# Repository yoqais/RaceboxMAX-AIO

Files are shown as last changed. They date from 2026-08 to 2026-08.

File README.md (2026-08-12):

# RaceboxMAX AIO

Wireless display and lap/drag timer for the RaceBox Micro. An ESP32-C6 reads
the logger's 25 Hz BLE telemetry and shows live speed, G-forces, lap times
and drag runs on a 2.42" SSD1309 OLED. Powered by a single 18650.

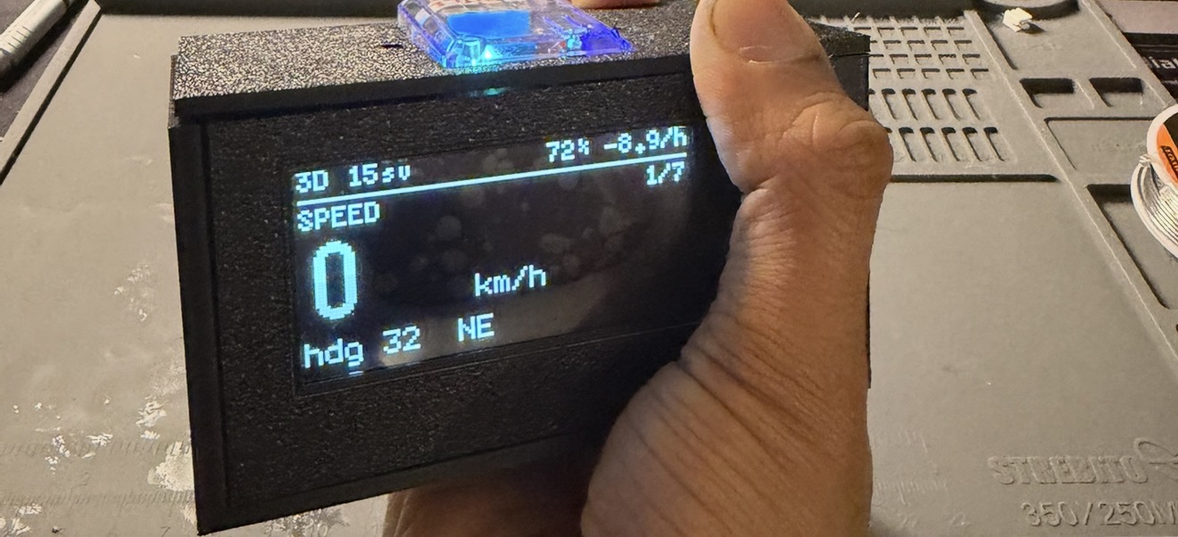
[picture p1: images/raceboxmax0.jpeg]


## Hardware

| Qty | Part | Notes |
|---|---|---|
| 1 | RaceBox Micro | The instrument. Accepts 3.5–16 V, draws ~25 mA recording |
| 1 | Seeed XIAO ESP32-C6 | 21 x 17.5 mm, BLE 5.3, USB-C |
| 1 | 2.42" SSD1309 OLED | 128 x 64, I2C mode, address 0x3C |
| 1 | Adafruit MAX17048 | LiPo fuel gauge, I2C, address 0x36 |
| 1 | Adafruit PowerBoost 1000C | 1 A charger, 5.2 V boost, load sharing |
| 1 | Protected 18650 | 3400 mAh. Protected cells run 69–70 mm, check holder fit |
| 1 | 470 uF electrolytic | Bulk cap across the XIAO's VBUS and GND |
| 3 | 6 x 6 mm tactile switch | Up, down, select |
| 1 | SPST toggle | Master power, wired to the PowerBoost EN pin |

No fuses and no external resistors. The protected cell's own PCB opens a
short in tens of microseconds, while a PPTC takes tens of milliseconds and
would never win that race. The I2C pull-ups are already on both breakouts.

## Wiring

The 18650 goe through the MAX17048's two parallel JST connectors into the
PowerBoost battery input, so the gauge sees the cell without sitting in the
way of anything. The PowerBoost 5.2 V rail feeds the XIAO's VBUS pin and the
RaceBox in parallel. Everything on I2C runs from the XIAO's 3V3 pin so the
logic levels match the C6's 3.3 V GPIO.

| Signal | XIAO pin | GPIO |
|---|---|---|
| I2C SDA | D4 | 22 |
| I2C SCL | D5 | 23 |
| Display RES | D3 | 21 |
| Button UP | D0 | 0 |
| Button DOWN | D1 | 1 |
| Button SELECT | D2 | 2 |

The display's DC and CS pads tie to ground. The XIAO's own BAT solder pads
stay empty, because the PowerBoost is the charger and two charger ICs on one
cell will fight each other.

The 470 uF cap goes as close to the XIAO's VBUS and GND pins as you can
solder it. The C6 pulls sharp current bursts on radio activity, and the sag
down a foot of wire causes brownout resets that look exactly like a firmware
bug. Watch polarity.

### Ground

Ground is one net, but three separate buses:

| Bus | Fed from | Carries |
|---|---|---|
| GND-A | PowerBoost G pin | XIAO, bulk cap |
| GND-C | XIAO GND pin | Display, fuel gauge |
| GND-B | PowerBoost GND pin | RaceBox, switch, buttons |

The I2C peripherals ground at the XIAO rather than at the PowerBoost. The C6
pulls roughly 300 mA in short bursts during radio activity and that current
has to return somewhere. Referencing the display and gauge to the same point
as their bus master makes any resulting offset common mode instead of putting
it across SDA and SCL.

## Power

| Load | On the 5.2 V rail |
|---|---|
| XIAO ESP32-C6 | ~70 mA |
| SSD1309 | ~50 mA depending on lit pixels |
| RaceBox Micro | ~25 mA |

Roughly 145 mA out, about 230 mA from the cell once boost losses and
quiescent draw are counted. That gives somewhere near 12 hours on a 3400 mAh
cell.

## Interface

Up, down and select. A 600 ms long-press on select backs out from anywhere.

A status bar is drawn across the top of every screen and no page can write
into it. It shows fix type and satellite count on the left, battery percent
and discharge rate in percent per hour on the right. The battery text is
right-aligned by measured width and the left label is suppressed if it would
not fit, so the two can never collide.

### Live page

Speed in MPH as the headline number, with lateral and longitudinal G,
heading and compass point, altitude, and horizontal accuracy underneath.

### Track page
Select a track and the display arms itself. Drive across the start/finish
line and timing begins automatically. Every crossing after that closes one
lap and opens the next. While running you get current lap, last lap and best
lap, with a checkered flag on a new personal best.

Thunderhill East 3 mile, West 2 mile and the 5 mile combined are preloaded.

**Before your first session**, each track needs its start/finish line
recorded. Gate coordinates ship empty because a gate has to be accurate to a
few metres and there is no useful default.

1. Select the track. The screen will read NO GATE SET.
2. Drive to the start/finish line, pointing the direction you race.
3. Press UP. The firmware builds a 30 m gate perpendicular to your heading
   and begins timing immediately.
4. Check the serial monitor. It prints the gate ready to paste into the
   tracks table so it survives a power cycle.

Captured gates live in RAM and clear on reboot until you paste them in.
Uploading tracks and gates from the menu is planned for a future update.

```
{ "T-Hill 5 Mile",  39.5372, -122.3310,  3.0f,  {0, 0, 0, 0, false} }
//     name       center lat  center lon  radius      gate
```

The center coordinates in the table are approximate and used only for the
proximity check with a 3 km radius. They are not accurate enough to be gates.

### Drag page

Standing start auto-arms after one second stationary and triggers on
movement, so there is no button press at the line. It captures 60 ft,
0–60 mph, and eighth and quarter mile with trap speeds, integrating distance
from speed against iTOW deltas.

A separate 60–0 mode arms above 62 mph, starts measuring when you drop
through 60, and reports braking distance in feet.

There is no rollout correction, so these read 0.2 to 0.3 s slower than a
dragstrip slip, which starts the clock after the car rolls a foot.

### Options page

State of charge, cell voltage, charge rate in percent per hour, hours
remaining, and the gauge's IC version, chip ID and alert flags.

## Firmware notes

Both timers run inside the BLE notify callback rather than the main loop, so
no 25 Hz sample is dropped while the display is mid-redraw.

Notifications are reassembled by a byte-level state machine that syncs on the
0xB5 0x62 header, reads the declared payload length, and verifies the
checksum before parsing. BLE can split an 88-byte message across fragments,
and assuming one notification equals one packet will bite you.

All field extraction uses memcpy rather than pointer casts. Reference code
written for the original ESP32 casts unaligned pointers, which works on
Xtensa because it has an unaligned-access exception handler. The C6 is
RISC-V.

The C6 has a dual-antenna design with an RF switch on GPIO14. Get that wrong
and BLE range collapses in a way that is maddening to debug.

### Libraries

- U8g2 by oliver
- Adafruit MAX1704X
- NimBLE-Arduino **2.x**

NimBLE 1.4.x will not compile on Arduino core 3.x. It was built against
ESP-IDF 4.4 and fails on a missing `esp_coexist_internal.h`. The C6 only
exists on core 3.x, so 2.x is the only option.

## Enclosure

Printed in PETG, six parts: screen face, enclosure body, enclosure lid, button backings, esp326c tray,
MAX17048 tray and PowerBoost tray.

Do not print in anything carbon-filled. The XIAO's BLE antenna is inside the
box and carbon fiber is conductive enough to kill it.

The RaceBox mounts on top of the case, outside, because its patch antenna
needs a clear view of the sky while the display needs to face the driver.
Those are 90 degrees apart and no arrangement satisfies both in one sealed
box. Metal below a patch antenna is harmless, metal above or beside it is
not, which is why the 18650 lives in the bottom compartment.

## What it does not do

It does not record anything. No SD card, no filesystem, no NVS. Best lap and
best drag times live in RAM and clear on power cycle. Captured gates do the
same, which is why they print to serial.

Downloading the RaceBox's internal recordings over BLE is possible and
documented in their protocol. The device streams History Data messages after
an unlock, and the lock state resets on every connection. It is not
implemented here because there is nowhere to put two hours of 25 Hz data
without adding storage.

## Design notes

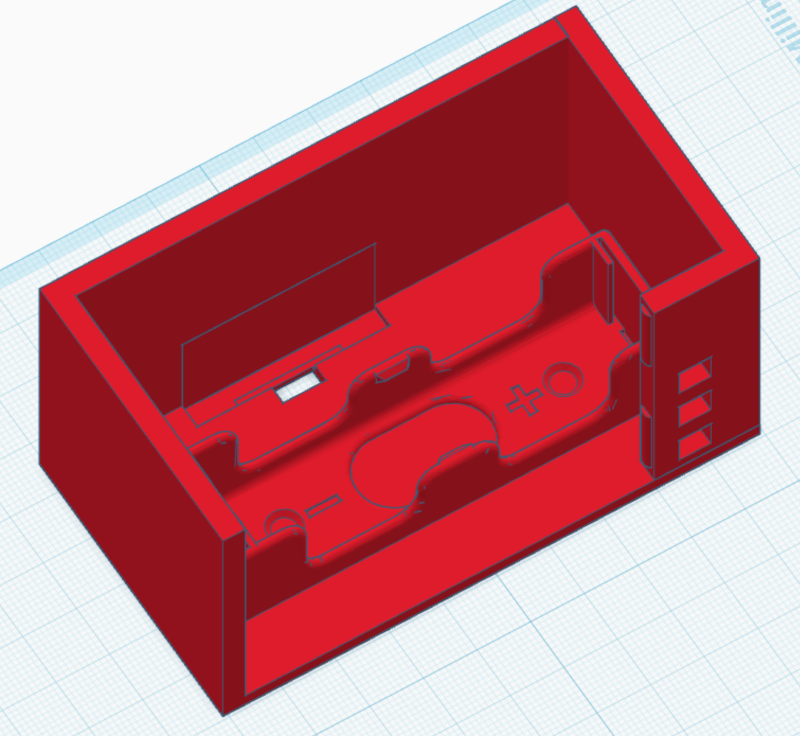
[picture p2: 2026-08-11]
images/housing.png

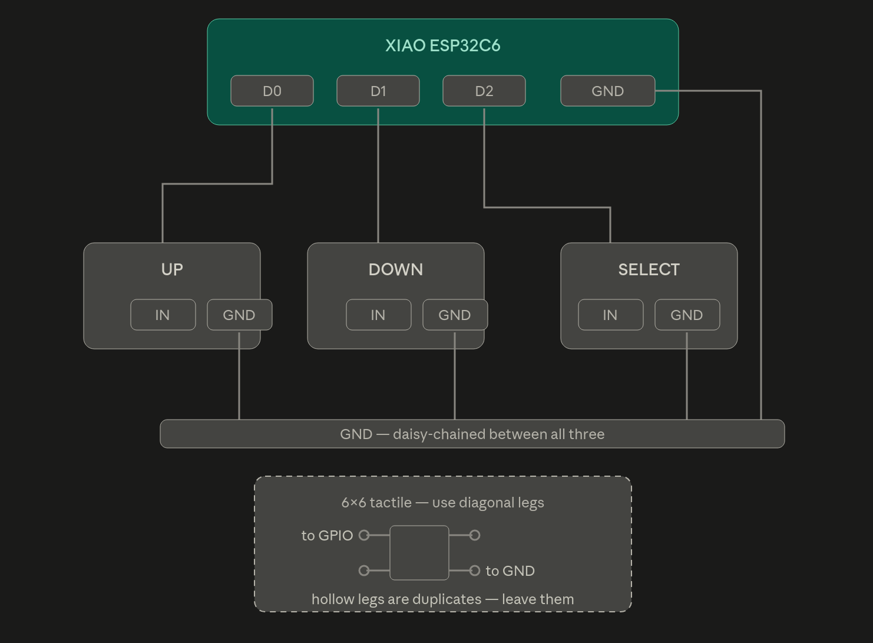
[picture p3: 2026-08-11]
diagrams/BTN_diagram.png

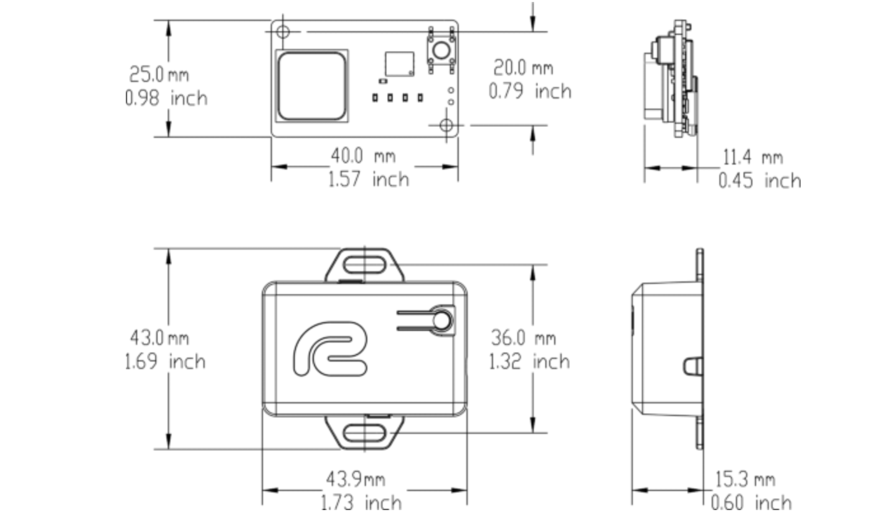
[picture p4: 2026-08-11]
diagrams/raceboxmicro_dimensions.png

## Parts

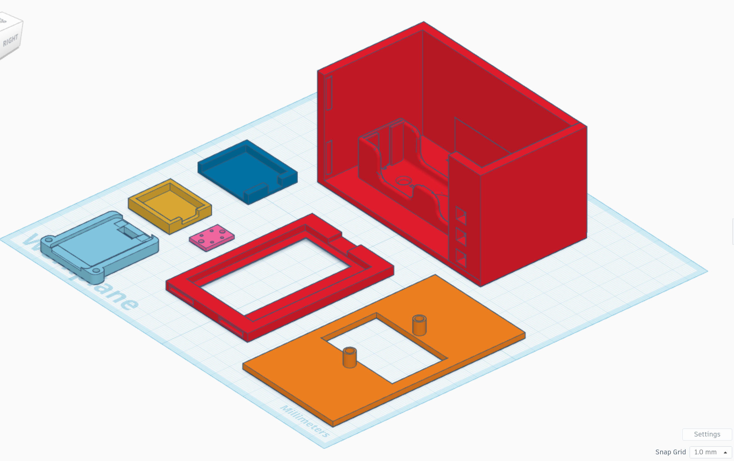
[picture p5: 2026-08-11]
images/parts.png

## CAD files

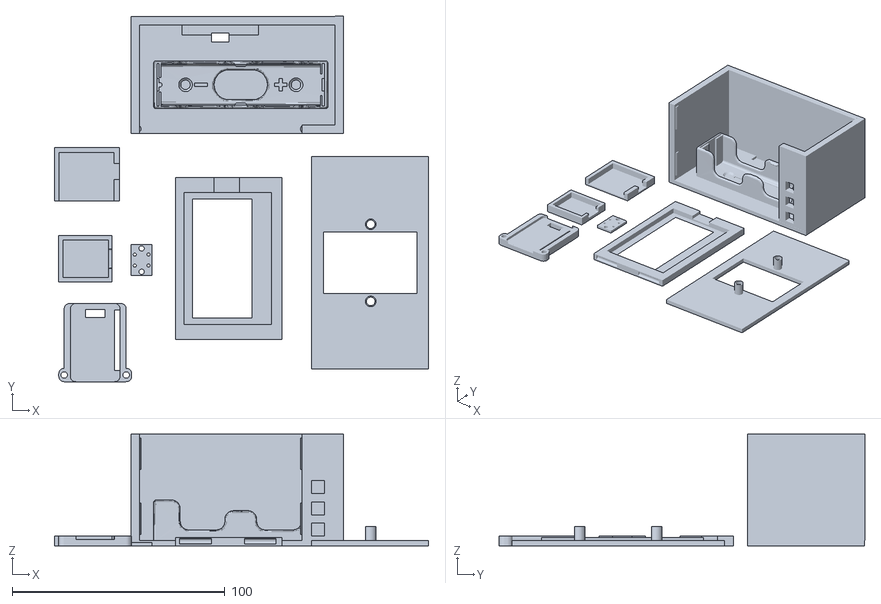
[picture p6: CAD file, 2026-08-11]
RaceboxMAX.stl
176.0 x 172.0 x 52.5

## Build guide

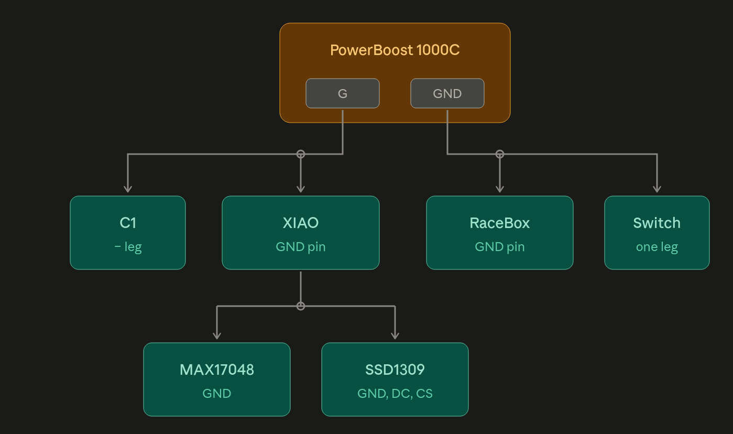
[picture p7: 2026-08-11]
diagrams/Wiring_Grounds_diagram.png

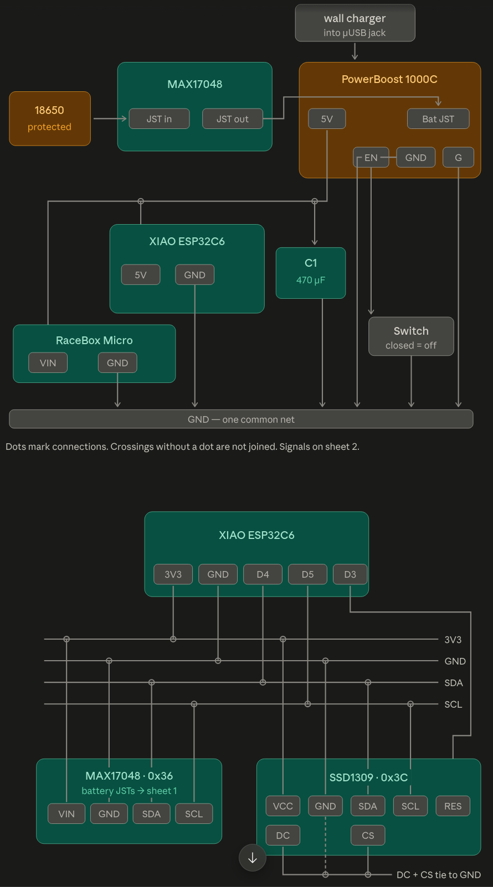
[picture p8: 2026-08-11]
diagrams/Wiring_Diagram.png

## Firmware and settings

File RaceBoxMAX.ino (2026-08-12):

#include <Wire.h>
#include <U8g2lib.h>
#include <Adafruit_MAX1704X.h>
#include <NimBLEDevice.h>
#include <string.h>
#include <math.h>

#define PIN_SDA        D4
#define PIN_SCL        D5
#define PIN_OLED_RES   D3
#define PIN_BTN_UP     D0
#define PIN_BTN_DOWN   D1
#define PIN_BTN_SELECT D2

// -------------------------------------------------------------- settings --
// Paste your RaceBox address here once you have it, e.g. "d1:9a:44:0f:22:31"
static const char* TARGET_ADDRESS = "";

static const uint32_t ADDRESS_HOLD_MS  = 5000;
static const uint32_t DRAW_INTERVAL_MS = 100;
static const uint32_t GAUGE_INTERVAL_MS = 1000;
static const uint32_t GAUGE_SETTLE_MS  = 2500;
static const uint32_t DEBOUNCE_MS      = 25;
static const uint32_t LONGPRESS_MS     = 600;
static const uint32_t MIN_LAP_MS       = 10000;   // ignore re-triggers
static const float    GATE_HALF_WIDTH_M = 15.0f;  // captured gates: 30 m wide

// ----------------------------------------------------------- BLE objects --
static NimBLEUUID UART_SERVICE_UUID("6E400001-B5A3-F393-E0A9-E50E24DCCA9E");
static NimBLEUUID TX_CHAR_UUID     ("6E400003-B5A3-F393-E0A9-E50E24DCCA9E");

U8G2_SSD1309_128X64_NONAME0_F_HW_I2C u8g2(U8G2_R0, PIN_OLED_RES, PIN_SCL, PIN_SDA);
Adafruit_MAX17048 gauge;

// ================================================================ screens ==
enum Screen {
  SC_SCAN, SC_ADDR, SC_LOST,
  SC_MAIN, SC_LIVE,
  SC_TRACKLIST, SC_TRACKRUN,
  SC_DRAGLIST, SC_DRAGRUN,
  SC_OPTIONS, SC_BATTERY
};
volatile Screen screen = SC_SCAN;

static const char* MAIN_ITEMS[]  = {"Live", "Track", "Drag", "Options"};
static const char* TRACK_ITEMS[] = {"< Back", "T-Hill East 3mi",
                                    "T-Hill West 2mi", "T-Hill 5 Mile"};
static const char* DRAG_ITEMS[]  = {"< Back", "Standing start",
                                    "60-0 braking", "Clear bests"};
static const char* OPT_ITEMS[]   = {"< Back", "Battery"};

uint8_t selMain = 0,  topMain = 0;
uint8_t selTrack = 0, topTrack = 0;
uint8_t selDrag = 0,  topDrag = 0;
uint8_t selOpt = 0,   topOpt = 0;

// ================================================================= tracks ==
struct Gate { double lat1, lon1, lat2, lon2; bool valid; };
struct TrackDef {
  const char* name;
  double cLat, cLon;      // approximate facility centre, proximity check only
  float  radiusKm;
  Gate   gate;
};

// Thunderhill Raceway Park, Willows CA. Centre is approximate and used ONLY
// to decide "are we at the track". Gates must be captured or hard-coded.
TrackDef tracks[] = {
  { "T-Hill East 3mi", 39.5372, -122.3310, 3.0f, {0,0,0,0,false} },
  { "T-Hill West 2mi", 39.5372, -122.3310, 3.0f, {0,0,0,0,false} },
  { "T-Hill 5 Mile",   39.5372, -122.3310, 3.0f, {0,0,0,0,false} },
};
const uint8_t TRACK_COUNT = sizeof(tracks) / sizeof(tracks[0]);
int8_t activeTrack = -1;

// ============================================================ live values ==
bool gaugeOK = false, displayOK = false;
float batPct = 0, batVolt = 0, batRate = 0;
uint16_t batIC = 0; uint8_t batChip = 0, batAlert = 0;

volatile bool connected = false, doConnect = false;
static NimBLEAddress targetAddr;
static bool haveTarget = false;
static NimBLERemoteCharacteristic* pTxChar = nullptr;
static NimBLEClient* pClient = nullptr;
char rbAddress[24] = "--:--:--:--:--:--";
char rbName[28]    = "unknown";
uint32_t addressShownAt = 0;

uint32_t rb_iTOW;
uint16_t rb_year; uint8_t rb_month, rb_day, rb_hour, rb_min, rb_sec;
uint8_t  rb_fixStatus, rb_numSVs, rb_battRaw;
int32_t  rb_lon, rb_lat, rb_mslAlt;
uint32_t rb_hAcc, rb_speed, rb_heading;
uint16_t rb_pdop;
int16_t  rb_gx, rb_gy, rb_gz, rb_rx, rb_ry, rb_rz;
uint32_t rbPackets = 0;

// ============================================================ lap timing ===
struct LapState {
  bool     havePrev;
  double   prevX, prevY;
  uint32_t prevITOW;
  bool     running;
  uint32_t startITOW;
  uint32_t lastLapMs, bestLapMs;
  uint16_t lapCount;
  bool     newBest;
  uint32_t newBestAt;
} lap;

// ============================================================ drag timing ==
enum DragMode  { DM_STANDING, DM_BRAKE };
enum DragState { DS_WAIT, DS_ARMED, DS_RUN, DS_DONE };
DragMode  dragMode  = DM_STANDING;
volatile DragState dragState = DS_WAIT;

struct DragRun {
  uint32_t t0;            // iTOW at launch / brake start
  double   dist;          // metres travelled
  uint32_t prevITOW;
  float    t60ft, t0_60, t1_8, t1_4;
  float    v1_8, v1_4;
  float    brakeDistFt, brakeFromMph;
  uint32_t stillSince;
} run;

float bestT0_60 = 0, bestT1_4 = 0, bestBrakeFt = 0;

// =========================================================== button types ==
// These MUST stay above the first function definition in the file. The
// Arduino IDE injects auto-generated prototypes just before the first
// function, so any type used in a signature has to already exist by then.
enum BtnEvent { EV_NONE, EV_UP, EV_DOWN, EV_SELECT, EV_BACK };

struct Btn {
  uint8_t pin; bool stable; bool lastRaw;
  uint32_t changedAt, pressedAt; bool longSent;
};
Btn bUp {PIN_BTN_UP,     true, true, 0, 0, false};
Btn bDn {PIN_BTN_DOWN,   true, true, 0, 0, false};
Btn bSel{PIN_BTN_SELECT, true, true, 0, 0, false};

// ================================================== safe field extraction ==
static inline uint16_t rdU16(const uint8_t* p){ uint16_t v; memcpy(&v,p,2); return v; }
static inline int16_t  rdI16(const uint8_t* p){ int16_t  v; memcpy(&v,p,2); return v; }
static inline uint32_t rdU32(const uint8_t* p){ uint32_t v; memcpy(&v,p,4); return v; }
static inline int32_t  rdI32(const uint8_t* p){ int32_t  v; memcpy(&v,p,4); return v; }

// ==================================================== unit helpers ========
float speedMps()  { return rb_speed / 1000.0f; }
float speedMph()  { return rb_speed * 0.00223694f; }
float headingDeg(){ return rb_heading / 100000.0f; }
float latG()      { return rb_gy / 1000.0f; }
float lonG()      { return rb_gx / 1000.0f; }
float rbInputV()  { return rb_battRaw / 10.0f; }
bool  haveFix()   { return rb_fixStatus == 3 || rb_fixStatus == 2; }

const char* compass(float d) {
  static const char* p[] = {"N","NE","E","SE","S","SW","W","NW"};
  return p[((int)((d + 22.5f) / 45.0f)) & 7];
}
const char* fixText(uint8_t f) {
  switch (f) { case 0: return "nofix"; case 2: return "2D"; case 3: return "3D"; }
  return "?";
}

// local flat projection, good to millimetres over a few km
static void projectTo(double lat, double lon, double lat0, double lon0,
                      double &x, double &y) {
  const double M_PER_DEG = 111320.0;
  x = (lon - lon0) * M_PER_DEG * cos(lat0 * M_PI / 180.0);
  y = (lat - lat0) * M_PER_DEG;
}

static double distanceKm(double la1, double lo1, double la2, double lo2) {
  double x, y;
  projectTo(la1, lo1, la2, lo2, x, y);
  return sqrt(x * x + y * y) / 1000.0;
}

// ==================================================== packet reassembly ====
#define PKT_MAX 160
static uint8_t pkt[PKT_MAX];
static size_t  pktLen = 0;

static bool checksumOK(const uint8_t* d, size_t len) {
  uint8_t a = 0, b = 0;
  for (size_t i = 2; i < len - 2; i++) { a += d[i]; b += a; }
  return (a == d[len - 2] && b == d[len - 1]);
}

void updateLapTiming();
void updateDrag();

static void parseDataMessage(const uint8_t* d) {
  rb_iTOW   = rdU32(d + 6);
  rb_year   = rdU16(d + 10);
  rb_month  = d[12]; rb_day = d[13];
  rb_hour   = d[14]; rb_min = d[15]; rb_sec = d[16];
  rb_fixStatus = d[26];
  rb_numSVs    = d[29];
  rb_lon    = rdI32(d + 30);
  rb_lat    = rdI32(d + 34);
  rb_mslAlt = rdI32(d + 42);
  rb_hAcc   = rdU32(d + 46);
  rb_speed  = rdU32(d + 54);
  rb_heading= rdU32(d + 58);
  rb_pdop   = rdU16(d + 70);
  rb_battRaw= d[73];
  rb_gx = rdI16(d + 74); rb_gy = rdI16(d + 76); rb_gz = rdI16(d + 78);
  rb_rx = rdI16(d + 80); rb_ry = rdI16(d + 82); rb_rz = rdI16(d + 84);
  rbPackets++;

  // run the timers here so no 25 Hz sample is ever missed
  if (screen == SC_TRACKRUN) updateLapTiming();
  if (screen == SC_DRAGRUN)  updateDrag();
}

static void handlePacket(const uint8_t* d, size_t len) {
  if (d[2] == 0xFF && d[3] == 0x01 && rdU16(d + 4) == 80) parseDataMessage(d);
}

static void feedByte(uint8_t b) {
  if (pktLen >= PKT_MAX) pktLen = 0;
  if (pktLen == 0) { if (b == 0xB5) pkt[pktLen++] = b; return; }
  if (pktLen == 1) {
    if (b == 0x62) pkt[pktLen++] = b;
    else if (b != 0xB5) pktLen = 0;
    return;
  }
  pkt[pktLen++] = b;
  if (pktLen >= 6) {
    size_t total = 6 + rdU16(pkt + 4) + 2;
    if (total > PKT_MAX) { pktLen = 0; return; }
    if (pktLen == total) {
      if (checksumOK(pkt, total)) handlePacket(pkt, total);
      pktLen = 0;
    }
  }
}

// ============================================== gate crossing detection ====
// Segment/segment intersection. t = fraction along the path segment.
static bool segIntersect(double ax,double ay,double bx,double by,
                         double cx,double cy,double dx,double dy, double &t) {
  double rx = bx-ax, ry = by-ay, sx = dx-cx, sy = dy-cy;
  double den = rx*sy - ry*sx;
  if (fabs(den) < 1e-12) return false;
  double tt = ((cx-ax)*sy - (cy-ay)*sx) / den;
  double uu = ((cx-ax)*ry - (cy-ay)*rx) / den;
  if (tt < 0 || tt > 1 || uu < 0 || uu > 1) return false;
  t = tt;
  return true;
}

void resetLap() {
  memset(&lap, 0, sizeof(lap));
}

void updateLapTiming() {
  if (activeTrack < 0) return;
  Gate &g = tracks[activeTrack].gate;
  if (!g.valid || !haveFix()) { lap.havePrev = false; return; }

  double lat = rb_lat / 1e7, lon = rb_lon / 1e7;
  double lat0 = (g.lat1 + g.lat2) * 0.5, lon0 = (g.lon1 + g.lon2) * 0.5;

  double px, py;  projectTo(lat, lon, lat0, lon0, px, py);
  double g1x, g1y, g2x, g2y;
  projectTo(g.lat1, g.lon1, lat0, lon0, g1x, g1y);
  projectTo(g.lat2, g.lon2, lat0, lon0, g2x, g2y);

  if (!lap.havePrev) {
    lap.havePrev = true;
    lap.prevX = px; lap.prevY = py; lap.prevITOW = rb_iTOW;
    return;
  }

  double t;
  if (segIntersect(lap.prevX, lap.prevY, px, py, g1x, g1y, g2x, g2y, t)) {
    // interpolate the exact crossing instant between the two 25 Hz samples
    int32_t dt = (int32_t)(rb_iTOW - lap.prevITOW);
    uint32_t cross = lap.prevITOW + (uint32_t)(t * dt);

    if (lap.running) {
      uint32_t lapMs = cross - lap.startITOW;
      if (lapMs >= MIN_LAP_MS) {
        lap.lastLapMs = lapMs;
        lap.lapCount++;
        if (lap.bestLapMs == 0 || lapMs < lap.bestLapMs) {
          lap.bestLapMs = lapMs;
          lap.newBest = true;
          lap.newBestAt = millis();
        }
        lap.startITOW = cross;
      }
    } else {
      lap.running = true;
      lap.startITOW = cross;
      lap.lapCount = 0;
    }
  }

  lap.prevX = px; lap.prevY = py; lap.prevITOW = rb_iTOW;
}

// build a gate perpendicular to the current heading, centred here
void captureGate() {
  if (activeTrack < 0 || !haveFix()) return;
  double lat = rb_lat / 1e7, lon = rb_lon / 1e7;
  double hdg = headingDeg() * M_PI / 180.0;

  // perpendicular unit vector in metres
  double px = cos(hdg), py = -sin(hdg);          // right-hand normal
  double mLat = GATE_HALF_WIDTH_M / 111320.0;
  double mLon = GATE_HALF_WIDTH_M / (111320.0 * cos(lat * M_PI / 180.0));

  Gate &g = tracks[activeTrack].gate;
  g.lat1 = lat + py * mLat;  g.lon1 = lon + px * mLon;
  g.lat2 = lat - py * mLat;  g.lon2 = lon - px * mLon;
  g.valid = true;

  resetLap();
  Serial.printf("GATE %s\n  {%.7f, %.7f, %.7f, %.7f, true}\n",
                tracks[activeTrack].name, g.lat1, g.lon1, g.lat2, g.lon2);
}

// ===================================================== drag mode timing ====
void resetDrag() {
  memset(&run, 0, sizeof(run));
  dragState = DS_WAIT;
}

void updateDrag() {
  float mph = speedMph();
  uint32_t now = rb_iTOW;

  if (dragMode == DM_STANDING) {
    switch (dragState) {
      case DS_WAIT:
        if (mph < 1.0f) {
          if (run.stillSince == 0) run.stillSince = now;
          if (now - run.stillSince > 1000) { dragState = DS_ARMED; }
        } else run.stillSince = 0;
        break;

      case DS_ARMED:
        if (mph > 1.0f) {
          memset(&run, 0, sizeof(run));
          run.t0 = now; run.prevITOW = now;
          dragState = DS_RUN;
        }
        break;

      case DS_RUN: {
        int32_t dt = (int32_t)(now - run.prevITOW);
        if (dt > 0 && dt < 500) run.dist += speedMps() * (dt / 1000.0);
        run.prevITOW = now;
        float el = (now - run.t0) / 1000.0f;

        if (run.t60ft == 0 && run.dist >= 18.288)  run.t60ft = el;
        if (run.t0_60 == 0 && mph >= 60.0f)        run.t0_60 = el;
        if (run.t1_8  == 0 && run.dist >= 201.168) { run.t1_8 = el; run.v1_8 = mph; }
        if (run.t1_4  == 0 && run.dist >= 402.336) {
          run.t1_4 = el; run.v1_4 = mph;
          dragState = DS_DONE;
          if (bestT1_4 == 0 || run.t1_4 < bestT1_4) bestT1_4 = run.t1_4;
          if (run.t0_60 > 0 && (bestT0_60 == 0 || run.t0_60 < bestT0_60))
            bestT0_60 = run.t0_60;
        }
        if (mph < 1.0f && el > 3.0f) dragState = DS_DONE;   // aborted
        break;
      }
      case DS_DONE: break;
    }
  } else {  // DM_BRAKE
    switch (dragState) {
      case DS_WAIT:
        if (mph >= 62.0f) dragState = DS_ARMED;
        break;
      case DS_ARMED:
        if (mph <= 60.0f) {
          memset(&run, 0, sizeof(run));
          run.t0 = now; run.prevITOW = now; run.brakeFromMph = mph;
          dragState = DS_RUN;
        }
        break;
      case DS_RUN: {
        int32_t dt = (int32_t)(now - run.prevITOW);
        if (dt > 0 && dt < 500) run.dist += speedMps() * (dt / 1000.0);
        run.prevITOW = now;
        if (mph < 1.0f) {
          run.brakeDistFt = run.dist * 3.28084;
          dragState = DS_DONE;
          if (bestBrakeFt == 0 || run.brakeDistFt < bestBrakeFt)
            bestBrakeFt = run.brakeDistFt;
        }
        if (mph > 70.0f) dragState = DS_WAIT;   // gave up braking
        break;
      }
      case DS_DONE: break;
    }
  }
}

// ================================================================ buttons ==
// returns 1 on release-after-short, 2 on long-press reached
uint8_t pollBtn(Btn &b) {
  uint8_t out = 0;
  bool raw = digitalRead(b.pin);          // LOW = pressed (INPUT_PULLUP)
  uint32_t now = millis();

  if (raw != b.lastRaw) { b.lastRaw = raw; b.changedAt = now; }
  if ((now - b.changedAt) > DEBOUNCE_MS && raw != b.stable) {
    b.stable = raw;
    if (!b.stable) { b.pressedAt = now; b.longSent = false; }   // pressed
    else if (!b.longSent) out = 1;                              // short release
  }
  if (!b.stable && !b.longSent && (now - b.pressedAt) > LONGPRESS_MS) {
    b.longSent = true;
    out = 2;
  }
  return out;
}

BtnEvent readButtons() {
  uint8_t u = pollBtn(bUp), d = pollBtn(bDn), s = pollBtn(bSel);
  if (s == 2) return EV_BACK;
  if (s == 1) return EV_SELECT;
  if (u)      return EV_UP;
  if (d)      return EV_DOWN;
  return EV_NONE;
}

// ================================================================ BLE glue ==
static void notifyCallback(NimBLERemoteCharacteristic*, uint8_t* data,
                           size_t len, bool) {
  for (size_t i = 0; i < len; i++) feedByte(data[i]);
}

class ClientCallbacks : public NimBLEClientCallbacks {
  void onConnect(NimBLEClient*) override { connected = true; }
  void onDisconnect(NimBLEClient*, int reason) override {
    connected = false; pTxChar = nullptr; screen = SC_LOST;
    Serial.printf("disconnected (%d)\n", reason);
  }
};

class ScanCallbacks : public NimBLEScanCallbacks {
  void onResult(const NimBLEAdvertisedDevice* dev) override {
    std::string name = dev->getName();
    if (name.rfind("RaceBox", 0) != 0) return;
    std::string addr = dev->getAddress().toString();
    if (strlen(TARGET_ADDRESS) > 0 && addr != std::string(TARGET_ADDRESS)) return;

    snprintf(rbName, sizeof(rbName), "%s", name.c_str());
    snprintf(rbAddress, sizeof(rbAddress), "%s", addr.c_str());
    Serial.printf("Found %s @ %s\n", rbName, rbAddress);

    targetAddr = dev->getAddress();
    haveTarget = true;
    NimBLEDevice::getScan()->stop();
    doConnect = true;
  }
};
static ScanCallbacks   scanCbs;
static ClientCallbacks clientCbs;

void startScan() {
  NimBLEScan* s = NimBLEDevice::getScan();
  s->setScanCallbacks(&scanCbs, false);
  s->setInterval(45); s->setWindow(15); s->setActiveScan(true);
  s->start(0, false, false);
  Serial.println("Scanning...");
}

bool connectToRaceBox() {
  if (!haveTarget) return false;
  pClient = NimBLEDevice::createClient();
  pClient->setClientCallbacks(&clientCbs, false);
  if (!pClient->connect(targetAddr)) {
    NimBLEDevice::deleteClient(pClient); pClient = nullptr; return false;
  }
  NimBLERemoteService* svc = pClient->getService(UART_SERVICE_UUID);
  if (!svc) return false;
  pTxChar = svc->getCharacteristic(TX_CHAR_UUID);
  if (!pTxChar) return false;
  return pTxChar->subscribe(true, notifyCallback);
}

// ================================================================ display ==
void drawStatusBar() {
  char right[24], left[20];
  u8g2.setFont(u8g2_font_5x8_tf);

  if (gaugeOK && millis() > GAUGE_SETTLE_MS)
    snprintf(right, sizeof(right), "%d%% %+.1f/h", (int)(batPct + 0.5f), batRate);
  else
    snprintf(right, sizeof(right), "--%% --/h");
  int rw = u8g2.getStrWidth(right);
  u8g2.drawStr(128 - rw, 7, right);

  if (connected) snprintf(left, sizeof(left), "%s %dsv", fixText(rb_fixStatus), rb_numSVs);
  else           snprintf(left, sizeof(left), "no link");

  if (u8g2.getStrWidth(left) <= 128 - rw - 4) u8g2.drawStr(0, 7, left);
  u8g2.drawHLine(0, 10, 128);
}

void drawList(const char* const* items, uint8_t count, uint8_t sel, uint8_t top) {
  u8g2.setFont(u8g2_font_7x14_tf);
  for (uint8_t i = 0; i < 3 && (top + i) < count; i++) {
    uint8_t idx = top + i;
    int y0 = 12 + i * 17;
    if (idx == sel) { u8g2.drawBox(0, y0, 122, 17); u8g2.setDrawColor(0); }
    u8g2.drawStr(3, y0 + 13, items[idx]);
    u8g2.setDrawColor(1);
  }
  if (count > 3) {
    int barH = 51 * 3 / count; if (barH < 8) barH = 8;
    int barY = 12 + (int)((51 - barH) * (float)top / (float)(count - 3));
    u8g2.drawFrame(124, 12, 4, 51);
    u8g2.drawBox(125, barY + 1, 2, barH - 2);
  }
}

void ensureVisible(uint8_t sel, uint8_t &top, uint8_t count) {
  if (count <= 3) { top = 0; return; }
  if (sel < top) top = sel;
  if (sel >= top + 3) top = sel - 2;
}

void fmtLap(char* out, size_t n, uint32_t ms) {
  if (ms == 0) { snprintf(out, n, "--:--.--"); return; }
  uint32_t m = ms / 60000, s = (ms % 60000) / 1000, c = (ms % 1000) / 10;
  snprintf(out, n, "%lu:%02lu.%02lu",
           (unsigned long)m, (unsigned long)s, (unsigned long)c);
}

void drawBigLeft(const char* s, int baseline) {
  u8g2.setFont(u8g2_font_logisoso24_tr);
  u8g2.drawStr(2, baseline, s);
}

// ---- screens ----
void scrScan() {
  u8g2.setFont(u8g2_font_7x14_tf);
  u8g2.drawStr(0, 32, "Searching for");
  u8g2.drawStr(0, 50, "RaceBox...");
}

void scrAddr() {
  char b[32];
  uint32_t left = (ADDRESS_HOLD_MS - (millis() - addressShownAt)) / 1000 + 1;
  u8g2.setFont(u8g2_font_7x14_tf);
  u8g2.drawStr(0, 26, "CONNECTED");
  u8g2.setFont(u8g2_font_6x12_tf);
  u8g2.drawStr(0, 42, rbAddress);
  u8g2.setFont(u8g2_font_5x8_tf);
  u8g2.drawStr(0, 54, rbName);
  snprintf(b, sizeof(b), "menu in %lus", (unsigned long)left);
  u8g2.drawStr(0, 63, b);
}

void scrLost() {
  u8g2.setFont(u8g2_font_7x14_tf);
  u8g2.drawStr(0, 32, "Link lost");
  u8g2.setFont(u8g2_font_6x12_tf);
  u8g2.drawStr(0, 50, "rescanning...");
}

void scrLive() {
  char b[32];
  snprintf(b, sizeof(b), "%d", (int)(speedMph() + 0.5f));
  drawBigLeft(b, 44);
  u8g2.setFont(u8g2_font_6x12_tf);
  u8g2.drawStr(2 + u8g2.getStrWidth(b) + 34, 44, "MPH");

  u8g2.setFont(u8g2_font_5x8_tf);
  snprintf(b, sizeof(b), "lat%+.2fg  lon%+.2fg", latG(), lonG());
  u8g2.drawStr(0, 54, b);
  snprintf(b, sizeof(b), "%s %03d  alt %dm  %.1fm",
           compass(headingDeg()), (int)headingDeg(),
           (int)(rb_mslAlt / 1000), rb_hAcc / 1000.0);
  u8g2.drawStr(0, 63, b);
}

void drawCheckerFlag(int x, int y) {
  for (int r = 0; r < 3; r++)
    for (int c = 0; c < 4; c++)
      if ((r + c) & 1) u8g2.drawBox(x + c * 5, y + r * 5, 5, 5);
  u8g2.drawFrame(x, y, 20, 15);
}
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
void loop() {
  uint32_t now = millis();
  static uint32_t lastDraw = 0, lastGauge = 0;

  handleEvent(readButtons());

  if (doConnect) {
    doConnect = false;
    if (connectToRaceBox()) {
      addressShownAt = now;
      screen = SC_ADDR;
      Serial.printf("*** RaceBox address: %s\n", rbAddress);
    } else { screen = SC_SCAN; startScan(); }
  }

  if (screen == SC_ADDR && (now - addressShownAt) >= ADDRESS_HOLD_MS) {
    screen = SC_MAIN; selMain = 0; topMain = 0;
  }
  if (screen == SC_LOST && !connected) { screen = SC_SCAN; startScan(); }

  if (gaugeOK && now - lastGauge >= GAUGE_INTERVAL_MS) {
    lastGauge = now;
    batVolt  = gauge.cellVoltage();
    batPct   = gauge.cellPercent();
    batRate  = gauge.chargeRate();
    batAlert = gauge.getAlertStatus();
    if (batPct < 0) batPct = 0;
    if (batPct > 100) batPct = 100;
  }

  if (displayOK && now - lastDraw >= DRAW_INTERVAL_MS) { lastDraw = now; draw(); }

  delay(2);
}

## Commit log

2026-08-12 Revise README for clarity and accuracy
    Updated descriptions for GND-C and track page sections. Corrected 'carbon filled' to 'carbon fiber'.
2026-08-12 Rename Racebox micro.stl to RaceboxMAX.stl
    [RaceboxMAX.stl]
